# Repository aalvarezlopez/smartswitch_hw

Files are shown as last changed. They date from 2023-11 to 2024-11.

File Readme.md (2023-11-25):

# Issues found while testing the first version

* Resisor package is 0201, change it to 0603
* I2C pins are located in a invalid pin. Correct location is:
   * TWD0 SPI\_SDA => PA3 
   * TWCK SPI\_CLK PA4
* I2C pull up resistors are missed (4k7)
* SPI pins are located in a invalid pin. Correct location is:
    * MISO => PA12
    * MOSI => PA13
    * SPCK => PA14
* DS18B20 can be serialized. Hot/Cold temperature of each radiator could use the same bus

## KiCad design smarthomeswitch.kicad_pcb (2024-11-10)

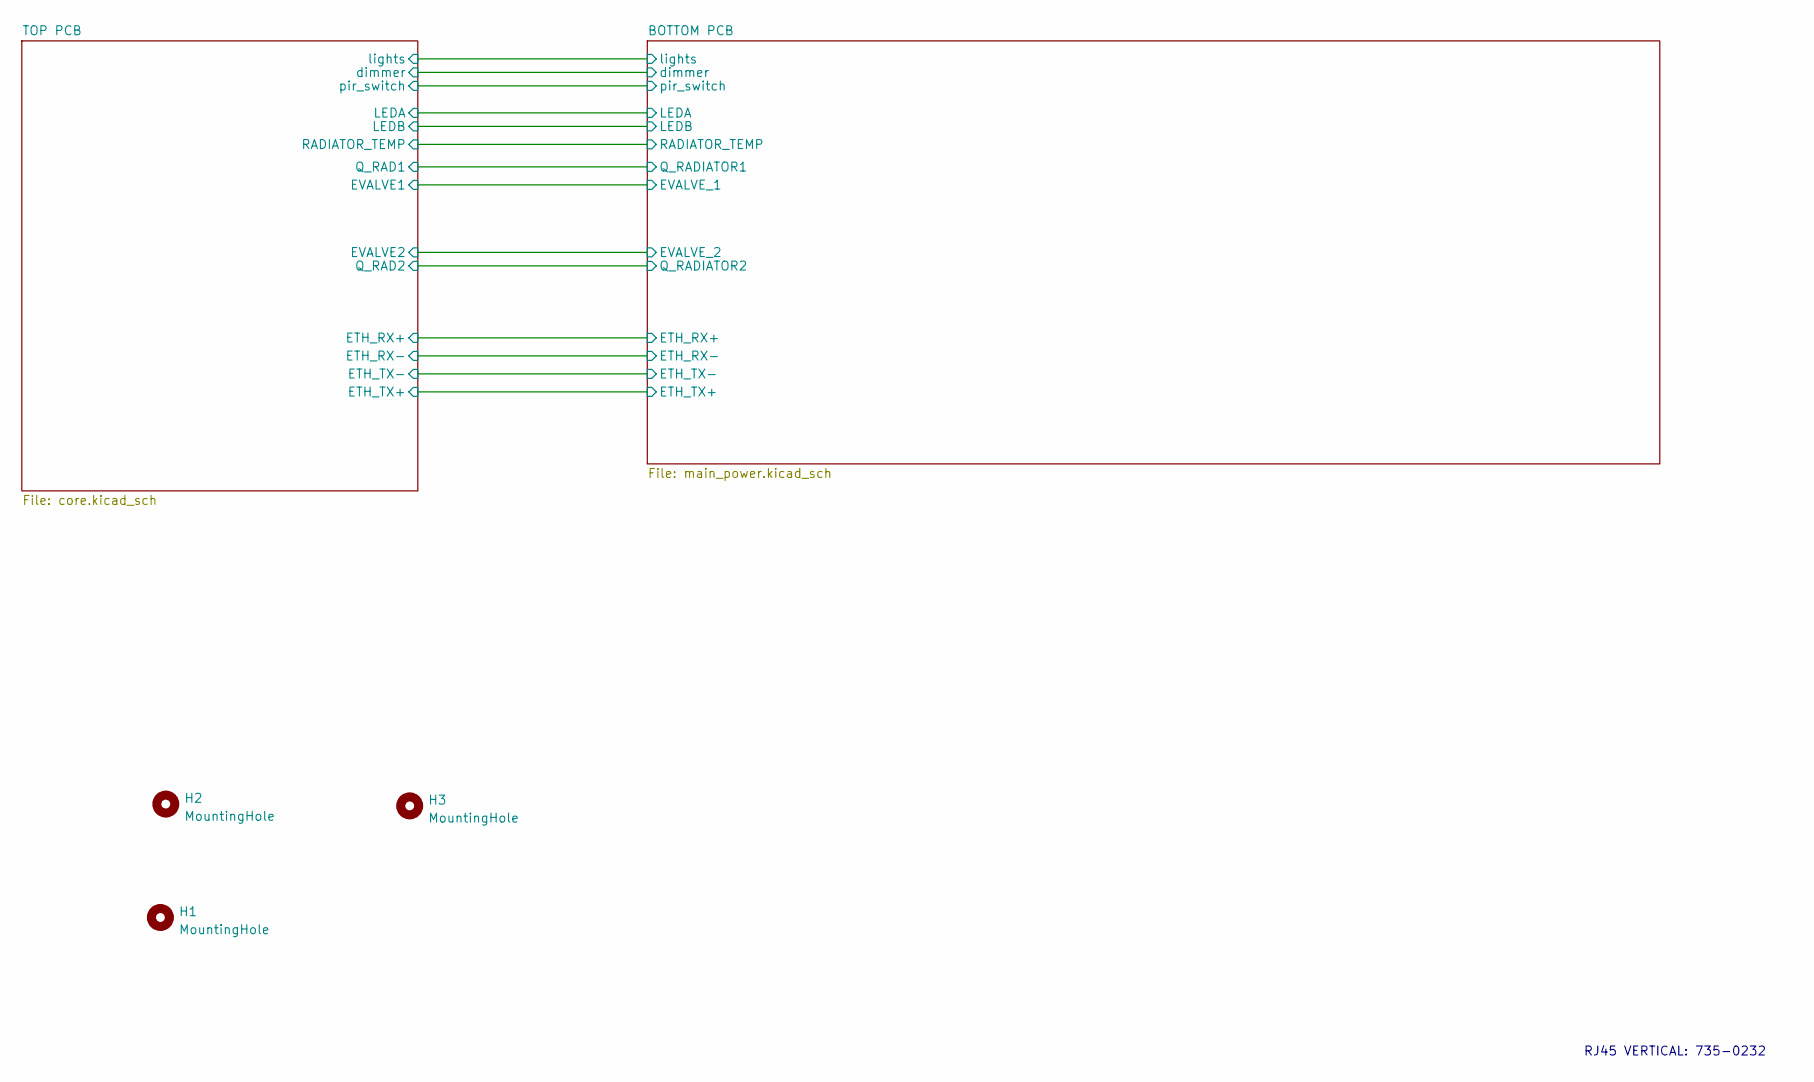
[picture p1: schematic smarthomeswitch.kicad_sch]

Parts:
H1, H2, H3: MountingHole; MountingHole_3.2mm_M3_ISO14580

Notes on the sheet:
RJ45 VERTICAL: 735-0232

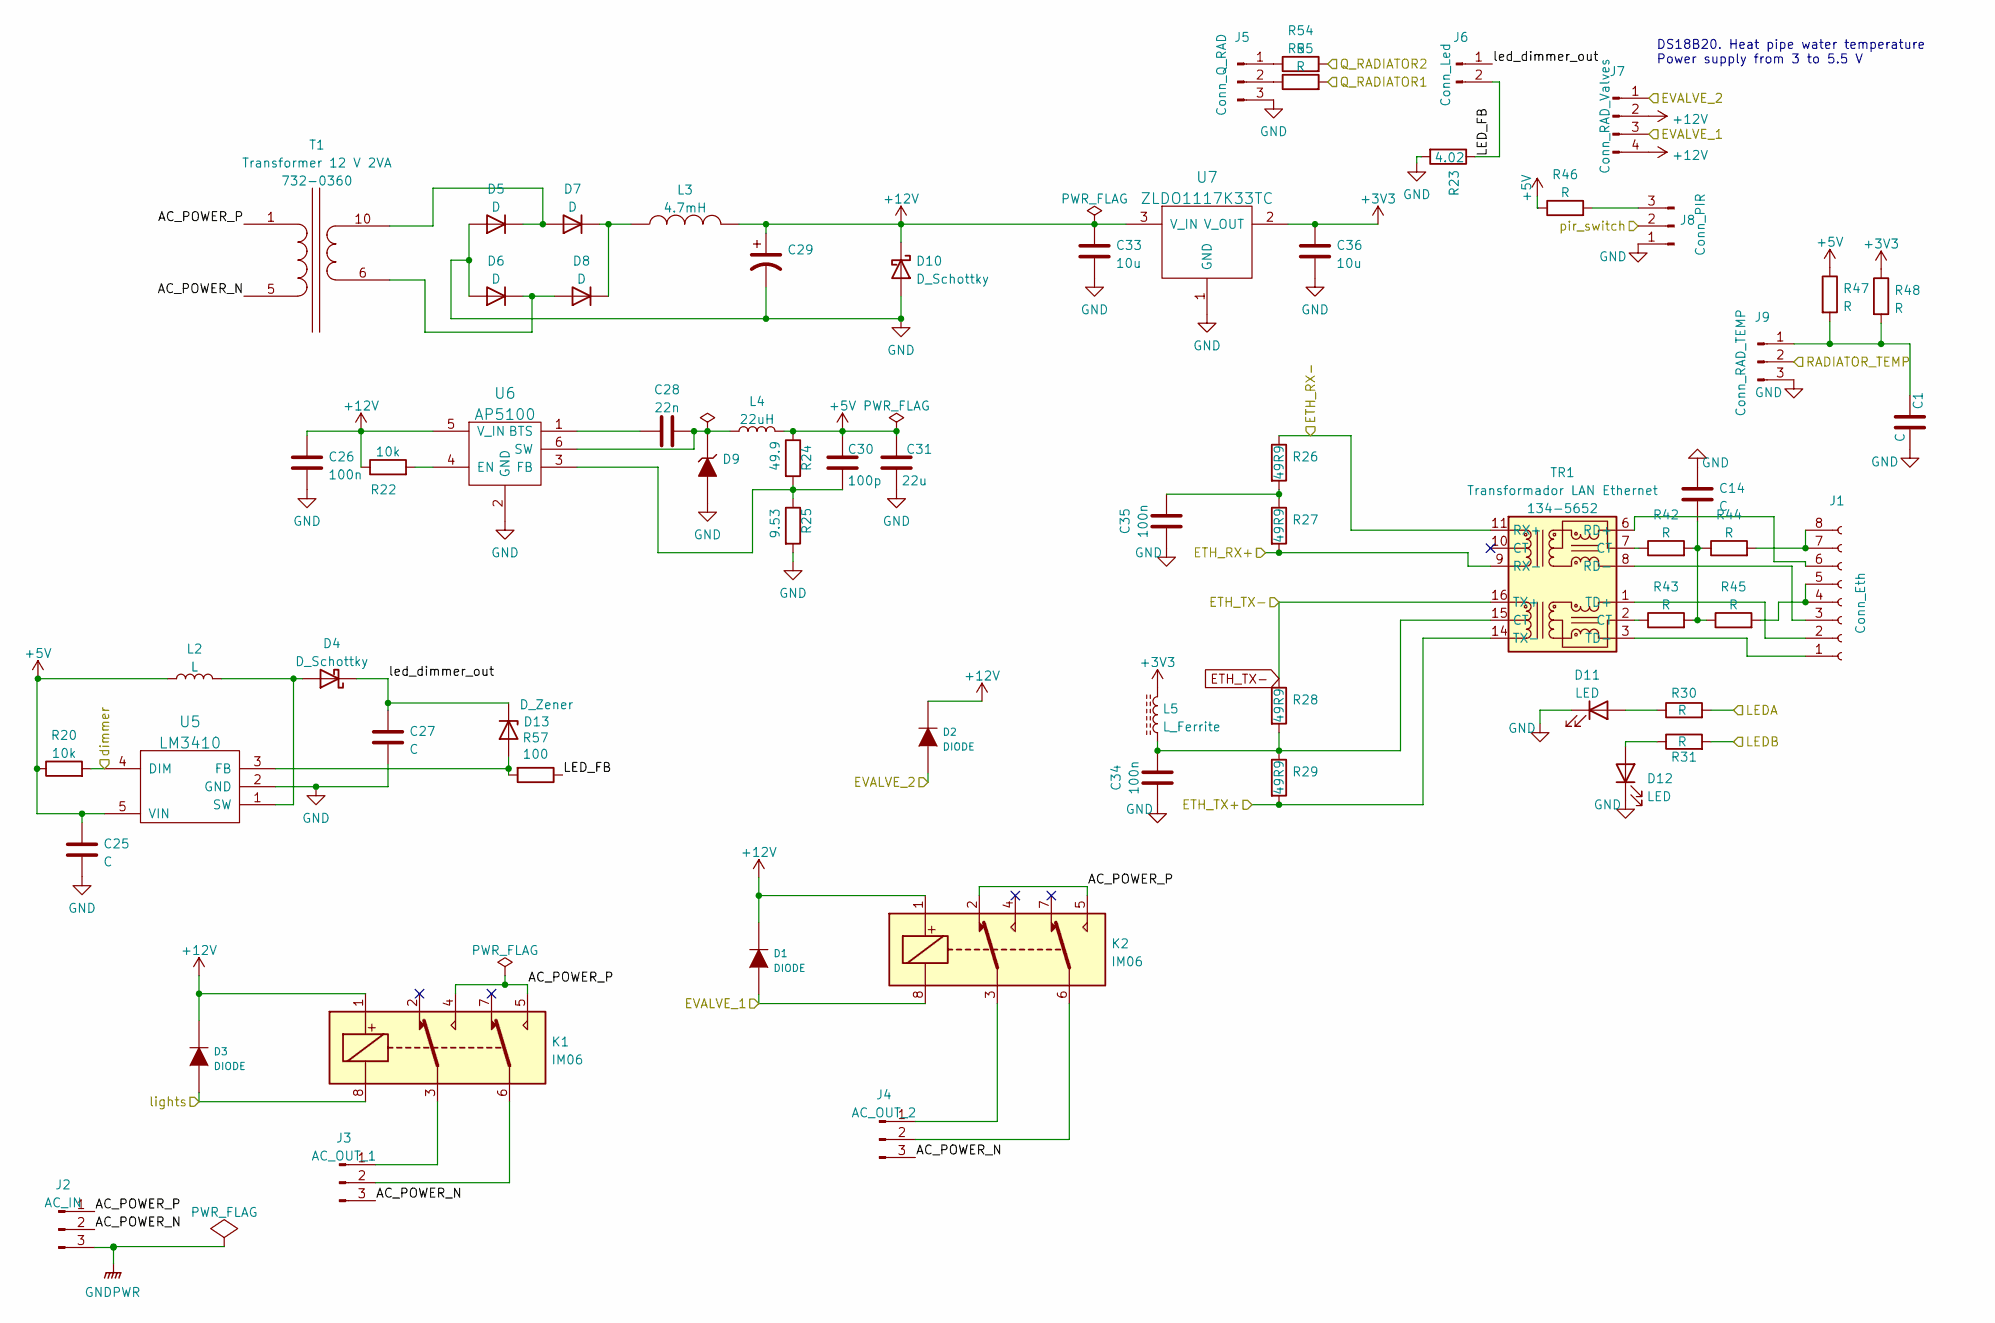
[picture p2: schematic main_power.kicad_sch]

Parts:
C1, C14, C25, C27: C; C_0603_1608Metric_Pad1.08x0.95mm_HandSolder
C26, C34, C35: 100n; C_0603_1608Metric_Pad1.08x0.95mm_HandSolder
C28: 22n; C_0603_1608Metric_Pad1.08x0.95mm_HandSolder
C29: C_Polarized_US; CP_Elec_6.3x5.8
C30: 100p; C_0603_1608Metric_Pad1.08x0.95mm_HandSolder
C31: 22u; CP_EIA-6032-15_Kemet-U_Pad2.25x2.35mm_HandSolder
C33, C36: 10u; CP_EIA-3528-12_Kemet-T_Pad1.50x2.35mm_HandSolder
D1, D2, D3: DIODE; D_SMA
D4: D_Schottky; D_Powermite2_AK
D5, D6, D7, D8: D; DO-213AB
D9: ZENER; D_SOD-323
D10: D_Schottky; D_SMA
D11, D12: LED; LED_0603_1608Metric_Pad1.05x0.95mm_HandSolder
D13: D_Zener; D_SMA_Handsoldering
J1: Conn_Eth; PinHeader_1x08_P2.54mm_Vertical
J2: AC_IN; TerminalBlock_bornier-3_P5.08mm
J3: AC_OUT_1; TerminalBlock_bornier-3_P5.08mm
J4: AC_OUT_2; TerminalBlock_bornier-3_P5.08mm
J5: Conn_Q_RAD; JST_PH_B3B-PH-K_1x03_P2.00mm_Vertical
J6: Conn_Led; JST_PH_B2B-PH-K_1x02_P2.00mm_Vertical
J7: Conn_RAD_Valves; JST_PH_B4B-PH-K_1x04_P2.00mm_Vertical
J8: Conn_PIR; JST_PH_B3B-PH-K_1x03_P2.00mm_Vertical
J9: Conn_RAD_TEMP; JST_PH_B3B-PH-K_1x03_P2.00mm_Vertical
K1, K2: IM06; IM06CTS
L2: L; L_1210_3225Metric_Pad1.42x2.65mm_HandSolder
L3: 4.7mH; L_12x12mm_H8mm
L4: 22uH; L_Wuerth_WE-PD2-Typ-L
L5: L_Ferrite; L_0805_2012Metric_Pad1.15x1.40mm_HandSolder
R20, R22: 10k; R_0603_1608Metric_Pad0.98x0.95mm_HandSolder
R23: 4.02; R_0603_1608Metric_Pad0.98x0.95mm_HandSolder
R24: 49.9; R_0603_1608Metric_Pad0.98x0.95mm_HandSolder
R25: 9.53; R_0603_1608Metric_Pad0.98x0.95mm_HandSolder
R26, R27, R28, R29: 49R9; R_0603_1608Metric_Pad0.98x0.95mm_HandSolder
R30, R31, R42, R43, R44, R45, R46, R47, R48, R54, R55: R; R_0603_1608Metric_Pad0.98x0.95mm_HandSolder
R57: 100; R_0603_1608Metric_Pad0.98x0.95mm_HandSolder
T1: Transformer 12 V 2VA; 12v_transformer_single
TR1: Transformador LAN Ethernet; SM13072APEL
U5: LM3410; SOT-23-5_HandSoldering
U6: AP5100; SOT26
U7: ZLDO1117K33TC; TO-252-3_TabPin2

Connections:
+3V3: C36.1, L5.2, R48.1, U7.2 (V_OUT); also elsewhere on the board
+5V: C25.1, C30.1, C31.1, L2.1, L4.2, R20.1, R24.1, R46.1, R47.1, U5.5 (VIN)
+12V: C26.1, C29.1, C33.1, D1.2 (K), D2.2 (K), D3.2 (K), D10.1 (K), J7.2, J7.4, K1.1, K2.1, L3.2, R22.1, U6.5 (V_IN), U7.3 (V_IN)
/BOTTOM PCB/AC_POWER_N: J2.2, J3.3, J4.3, T1.5 (AB)
/BOTTOM PCB/AC_POWER_P: J2.1, K1.4, K1.5, K2.2, K2.5, T1.1 (AA)
/BOTTOM PCB/EVALVE_1: D1.1 (A), J7.3, K2.8; also elsewhere on the board
/BOTTOM PCB/EVALVE_2: D2.1 (A), J7.1; also elsewhere on the board
/BOTTOM PCB/LEDA: R30.2; also elsewhere on the board
/BOTTOM PCB/LEDB: R31.2; also elsewhere on the board
/BOTTOM PCB/LED_FB: J6.2, R23.1, R57.1
/BOTTOM PCB/Q_RADIATOR1: R55.2; also elsewhere on the board
/BOTTOM PCB/Q_RADIATOR2: R54.2; also elsewhere on the board
/BOTTOM PCB/RADIATOR_TEMP: J9.2; also elsewhere on the board
/BOTTOM PCB/dimmer: R20.2, U5.4 (DIM); also elsewhere on the board
/BOTTOM PCB/led_dimmer_out: C27.1, D4.1 (K), D13.1 (K), J6.1
/BOTTOM PCB/lights: D3.1 (A), K1.8; also elsewhere on the board
/BOTTOM PCB/pir_switch: J8.2; also elsewhere on the board
/TOP PCB/ethernet/ETH_RX+: R27.2, TR1.9 (RX-); also elsewhere on the board
/TOP PCB/ethernet/ETH_RX-: R26.1, TR1.11 (RX+); also elsewhere on the board
/TOP PCB/ethernet/ETH_TX+: R29.2, TR1.14 (TX-); also elsewhere on the board
ETH_TX-: R28.1, TR1.16 (TX+); also elsewhere on the board
GND: C1.2, C14.1, C25.2, C26.2, C27.2, C29.2, C31.2, C33.2, C34.1, C35.1, C36.2, D5.2 (A), D6.2 (A), D9.2 (A), D10.2 (A), D11.1 (K), D12.1 (K), J5.3, J8.1, J9.3, R23.2, R25.2, U5.2 (GND), U6.2 (GND), U7.1 (GND); also elsewhere on the board
GNDPWR: J2.3
unnamed: C1.1, J9.1, R47.2, R48.2
unnamed: C14.2, R42.2, R43.2, R44.1, R45.1
unnamed: C28.1, U6.1 (BTS)
unnamed: C28.2, D9.1 (K), L4.1, U6.6 (SW)
unnamed: C30.2, R24.2, R25.1, U6.3 (FB)
unnamed: C34.2, L5.1, R28.2, R29.1, TR1.15 (CT)
unnamed: C35.2, R26.2, R27.1
unnamed: D4.2 (A), L2.2, U5.1 (SW)
unnamed: D5.1 (K), D7.2 (A), T1.10 (SA)
unnamed: D6.1 (K), D8.2 (A), T1.6 (SD)
unnamed: D7.1 (K), D8.1 (K), L3.1
unnamed: D11.2 (A), R30.1
unnamed: D12.2 (A), R31.1
unnamed: D13.2 (A), R57.2, U5.3 (FB)
unnamed: J1.1, TR1.3 (TD-)
unnamed: J1.2, TR1.1 (TD+)
unnamed: J1.3, TR1.8 (RD-)
unnamed: J1.4, J1.5, R45.2
unnamed: J1.6, TR1.6 (RD+)
unnamed: J1.7, J1.8, R44.2
unnamed: J3.1, K1.3
unnamed: J3.2, K1.6
unnamed: J4.1, K2.3
unnamed: J4.2, K2.6
unnamed: J5.1, R54.1
unnamed: J5.2, R55.1
unnamed: J8.3, R46.2
unnamed: R22.2, U6.4 (EN)
unnamed: R42.1, TR1.7 (CT)
unnamed: R43.1, TR1.2 (CT)

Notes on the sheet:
DS18B20. Heat pipe water temperature Power supply from 3 to 5.5 V

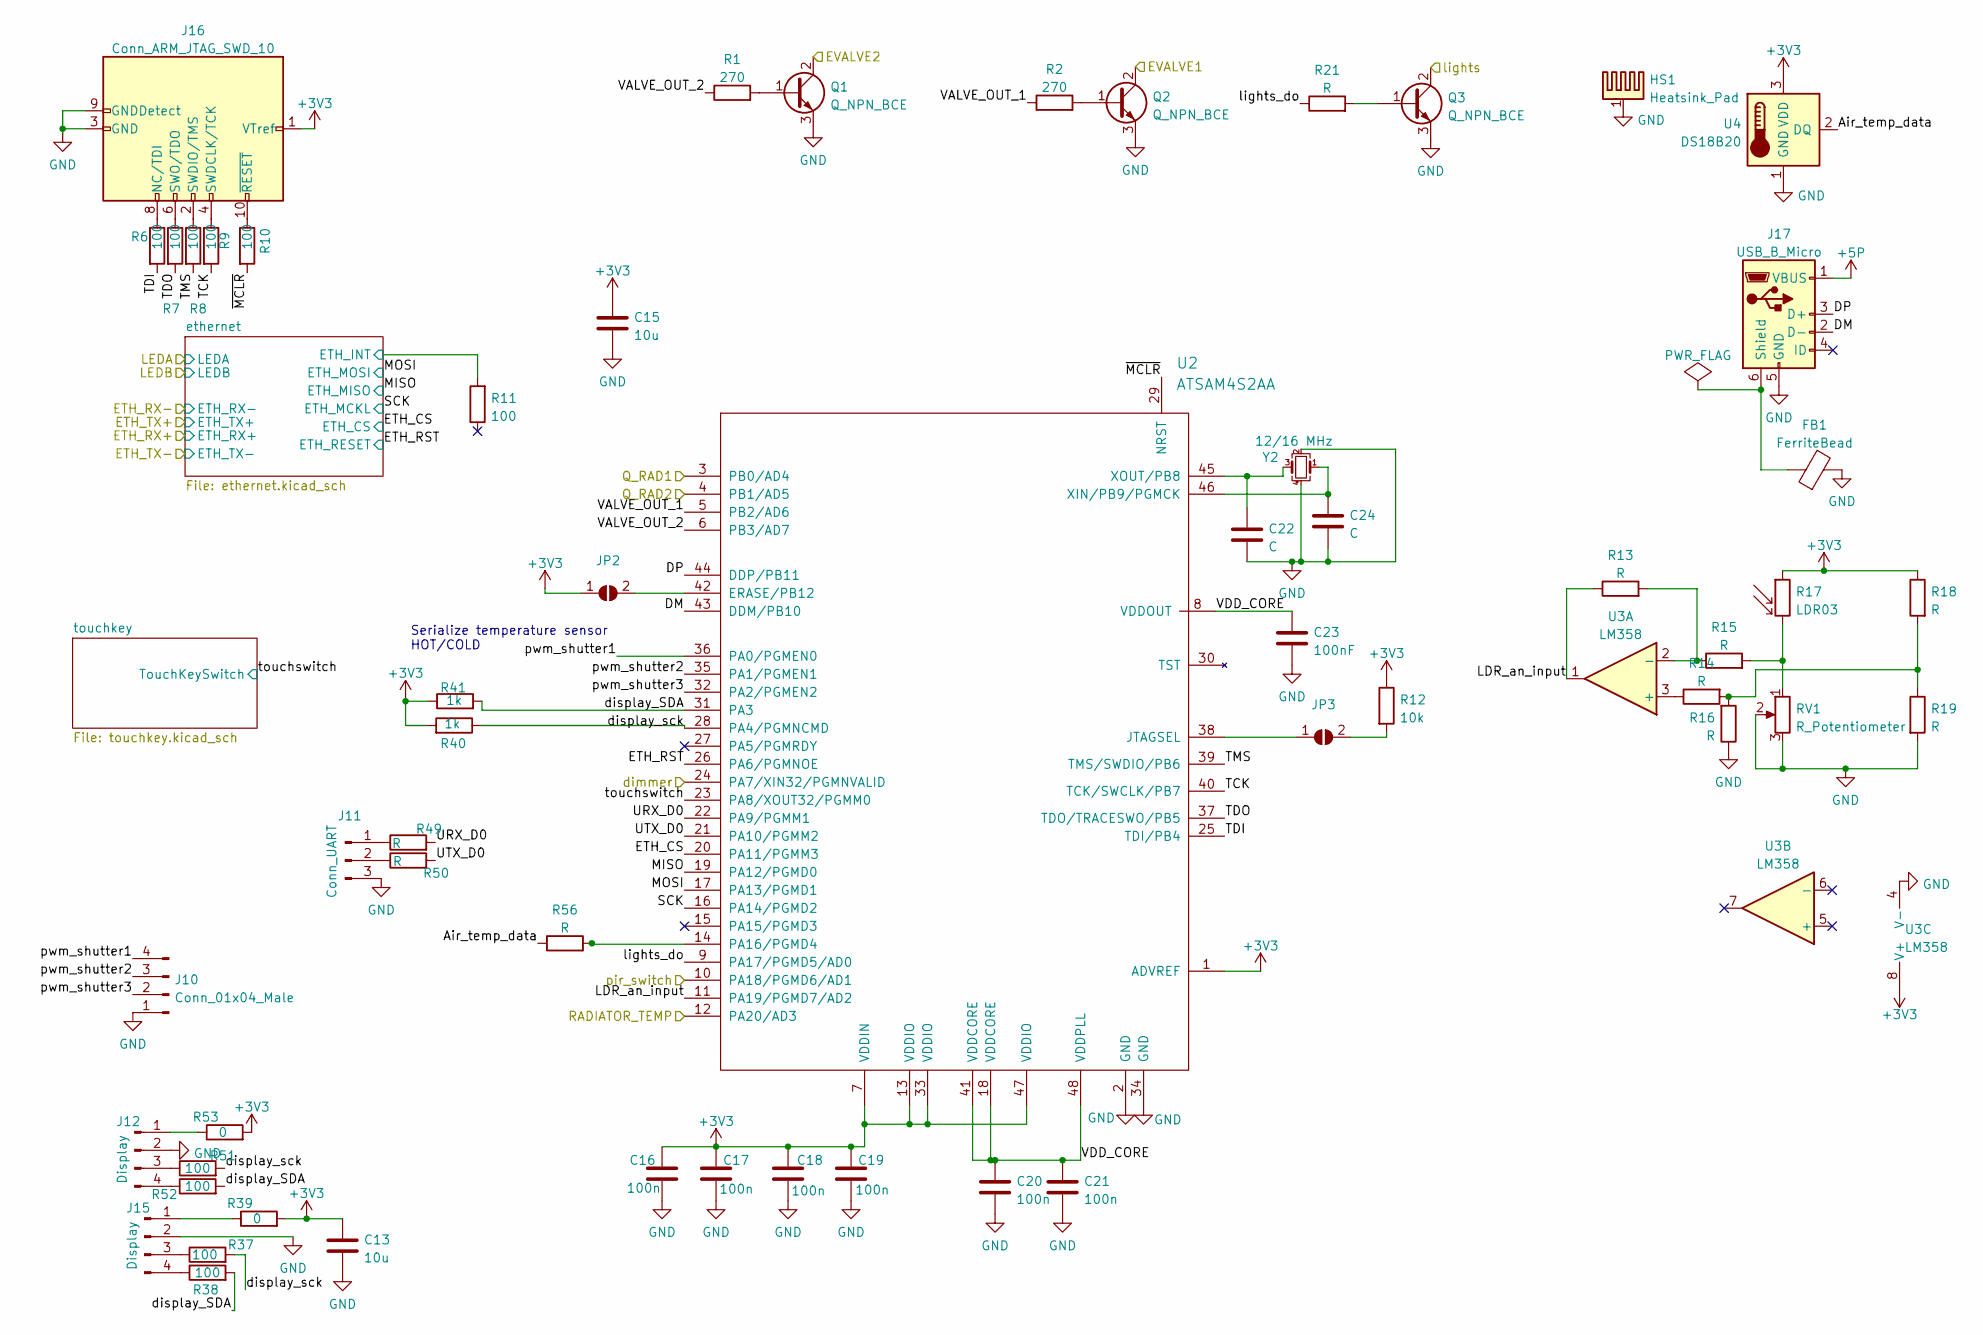
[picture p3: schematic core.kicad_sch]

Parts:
C13, C15: 10u; CP_EIA-3528-12_Kemet-T_Pad1.50x2.35mm_HandSolder
C16, C17, C18, C19, C20, C21: 100n; C_0603_1608Metric_Pad1.08x0.95mm_HandSolder
C22, C24: C; C_0603_1608Metric_Pad1.08x0.95mm_HandSolder
C23: 100nF; C_0603_1608Metric_Pad1.08x0.95mm_HandSolder
FB1: FerriteBead; L_1206_3216Metric_Pad1.22x1.90mm_HandSolder
HS1: Heatsink_Pad; Heatsink_AAVID_573300D00010G_TO-263
J10: Conn_01x04_Male; JST_PH_B4B-PH-K_1x04_P2.00mm_Vertical
J11: Conn_UART; JST_PH_B3B-PH-K_1x03_P2.00mm_Vertical
J12, J15: Display; PinHeader_1x04_P2.54mm_Vertical
J16: Conn_ARM_JTAG_SWD_10; JTAG_50mil
J17: USB_B_Micro; USB_Micro-B_Molex_47346-0001
JP2, JP3: SolderJumper_2_Open; SolderJumper-2_P1.3mm_Open_TrianglePad1.0x1.5mm
Q1, Q2, Q3: Q_NPN_BCE; SOT-223-3_TabPin2
R1, R2: 270; R_0603_1608Metric_Pad0.98x0.95mm_HandSolder
R6, R7, R8, R9, R10, R11, R37, R38, R51, R52: 100; R_0603_1608Metric_Pad0.98x0.95mm_HandSolder
R12: 10k; R_0603_1608Metric_Pad0.98x0.95mm_HandSolder
R13, R14, R15, R16, R18, R19, R21, R49, R50, R56: R; R_0603_1608Metric_Pad0.98x0.95mm_HandSolder
R17: LDR03; R_Axial_DIN0204_L3.6mm_D1.6mm_P1.90mm_Vertical
R39, R53: 0; R_0603_1608Metric_Pad0.98x0.95mm_HandSolder
R40, R41: 1k; R_0603_1608Metric_Pad0.98x0.95mm_HandSolder
RV1: R_Potentiometer; Potentiometer_Bourns_TC33X_Vertical
U2: ATSAM4S2AA; LQFP-48_7x7mm_P0.5mm
U3: LM358; SOIC-8_3.9x4.9mm_P1.27mm
U4: DS18B20; TO-92_Inline
Y2: 12/16 MHz; Crystal_SMD_5032-4Pin_5.0x3.2mm

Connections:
+3V3: C13.1, C15.1, C16.1, C17.1, C18.1, C19.1, J16.1 (VTref), JP2.1 (A), R12.1, R17.1, R18.1, R39.2, R40.2, R41.1, R53.2, U2.1 (ADVREF), U2.7 (VDDIN), U2.13 (VDDIO), U2.33 (VDDIO), U2.47 (VDDIO), U3.8 (V+), U4.3 (VDD); also elsewhere on the board
+5P: J17.1 (VBUS)
/BOTTOM PCB/EVALVE_1: Q2.2 (C); also elsewhere on the board
/BOTTOM PCB/EVALVE_2: Q1.2 (C); also elsewhere on the board
/BOTTOM PCB/Q_RADIATOR1: U2.3 (PB0/AD4); also elsewhere on the board
/BOTTOM PCB/Q_RADIATOR2: U2.4 (PB1/AD5); also elsewhere on the board
/BOTTOM PCB/RADIATOR_TEMP: U2.12 (PA20/AD3); also elsewhere on the board
/BOTTOM PCB/dimmer: U2.24 (PA7/XIN32/PGMNVALID); also elsewhere on the board
/BOTTOM PCB/lights: Q3.2 (C); also elsewhere on the board
/BOTTOM PCB/pir_switch: U2.10 (PA18/PGMD6/AD1); also elsewhere on the board
/TOP PCB/Air_temp_data: R56.1, U4.2 (DQ)
/TOP PCB/DM: J17.2 (D-), U2.43 (DDM/PB10)
/TOP PCB/DP: J17.3 (D+), U2.44 (DDP/PB11)
/TOP PCB/ETH_CS: U2.20 (PA11/PGMM3); also elsewhere on the board
/TOP PCB/ETH_RST: U2.26 (PA6/PGMNOE); also elsewhere on the board
/TOP PCB/LDR_an_input: R13.1, U2.11 (PA19/PGMD7/AD2), U3.1
/TOP PCB/MISO: U2.19 (PA12/PGMD0); also elsewhere on the board
/TOP PCB/MOSI: U2.17 (PA13/PGMD1); also elsewhere on the board
/TOP PCB/SCK: U2.16 (PA14/PGMD2); also elsewhere on the board
/TOP PCB/TCK: R9.2, U2.40 (TCK/SWCLK/PB7)
/TOP PCB/TDI: R6.2, U2.25 (TDI/PB4)
/TOP PCB/TDO: R7.2, U2.37 (TDO/TRACESWO/PB5)
/TOP PCB/TMS: R8.2, U2.39 (TMS/SWDIO/PB6)
/TOP PCB/URX_D0: R49.2, U2.22 (PA9/PGMM1)
/TOP PCB/UTX_D0: R50.2, U2.21 (PA10/PGMM2)
/TOP PCB/VALVE_OUT_1: R2.1, U2.5 (PB2/AD6)
/TOP PCB/VALVE_OUT_2: R1.1, U2.6 (PB3/AD7)
/TOP PCB/VDD_CORE: C20.1, C21.1, C23.1, U2.8 (VDDOUT), U2.18 (VDDCORE), U2.41 (VDDCORE), U2.48 (VDDPLL)
/TOP PCB/display_SDA: R38.2, R41.2, R52.2, U2.31 (PA3)
/TOP PCB/display_sck: R37.2, R40.1, R51.2, U2.28 (PA4/PGMNCMD)
/TOP PCB/ethernet/ETH_INT: R11.2; also elsewhere on the board
/TOP PCB/lights_do: R21.1, U2.9 (PA17/PGMD5/AD0)
/TOP PCB/pwm_shutter1: J10.4, U2.36 (PA0/PGMEN0)
/TOP PCB/pwm_shutter2: J10.3, U2.35 (PA1/PGMEN1)
/TOP PCB/pwm_shutter3: J10.2, U2.32 (PA2/PGMEN2)
/TOP PCB/touchswitch: U2.23 (PA8/XOUT32/PGMM0); also elsewhere on the board
/TOP PCB/~MCLR: R10.2, U2.29 (NRST)
GND: C13.2, C15.2, C16.2, C17.2, C18.2, C19.2, C20.2, C21.2, C22.2, C23.2, C24.2, FB1.2, HS1.1, J10.1, J11.3, J12.2, J15.2, J16.3 (GND), J16.5 (GND), J16.9 (GNDDetect), J17.5 (GND), Q1.3 (E), Q2.3 (E), Q3.3 (E), R16.1, R19.2, RV1.2, RV1.3, U2.2 (GND), U2.34 (GND), U3.4 (V-), U4.1 (GND), Y2.2, Y2.4; also elsewhere on the board
unnamed: C22.1, U2.45 (XOUT/PB8), Y2.3
unnamed: C24.1, U2.46 (XIN/PB9/PGMCK), Y2.1
unnamed: FB1.1, J17.6 (Shield)
unnamed: J11.1, R49.1
unnamed: J11.2, R50.1
unnamed: J12.1, R53.1
unnamed: J12.3, R51.1
unnamed: J12.4, R52.1
unnamed: J15.1, R39.1
unnamed: J15.3, R37.1
unnamed: J15.4, R38.1
unnamed: J16.2 (SWDIO/TMS), R8.1
unnamed: J16.4 (SWDCLK/TCK), R9.1
unnamed: J16.6 (SWO/TDO), R7.1
unnamed: J16.8 (NC/TDI), R6.1
unnamed: J16.10 (~RESET), R10.1
unnamed: JP2.2 (B), U2.42 (ERASE/PB12)
unnamed: JP3.1 (A), U2.38 (JTAGSEL)
unnamed: JP3.2 (B), R12.2
unnamed: Q1.1 (B), R1.2
unnamed: Q2.1 (B), R2.2
unnamed: Q3.1 (B), R21.2
unnamed: R13.2, R15.1, U3.2 (-)
unnamed: R14.1, U3.3 (+)
unnamed: R14.2, R16.2, R18.2, R19.1
unnamed: R15.2, R17.2, RV1.1
unnamed: R56.2, U2.14 (PA16/PGMD4)

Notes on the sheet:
Serialize temperature sensor HOT/COLD

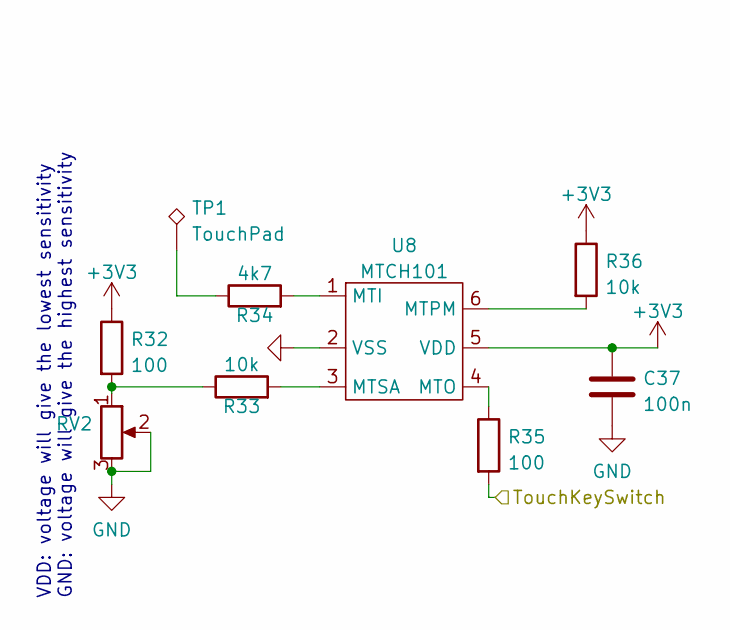
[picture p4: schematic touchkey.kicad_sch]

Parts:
C37: 100n; C_0603_1608Metric_Pad1.08x0.95mm_HandSolder
R32, R35: 100; R_0603_1608Metric_Pad0.98x0.95mm_HandSolder
R33, R36: 10k; R_0603_1608Metric_Pad0.98x0.95mm_HandSolder
R34: 4k7; R_0603_1608Metric_Pad0.98x0.95mm_HandSolder
RV2: R_Potentiometer; Potentiometer_Bourns_TC33X_Vertical
TP1: TouchPad; SolderWire-0.15sqmm_1x01_D0.5mm_OD1.5mm
U8: MTCH101; SOT-23-6_Handsoldering

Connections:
+3V3: C37.1, R32.1, R36.1, U8.5 (VDD); also elsewhere on the board
/TOP PCB/touchswitch: R35.2; also elsewhere on the board
GND: C37.2, RV2.2, RV2.3, U8.2 (VSS); also elsewhere on the board
unnamed: R32.2, R33.1, RV2.1
unnamed: R33.2, U8.3 (MTSA)
unnamed: R34.1, TP1.1
unnamed: R34.2, U8.1 (MTI)
unnamed: R35.1, U8.4 (MTO)
unnamed: R36.2, U8.6 (MTPM)

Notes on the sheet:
VDD: voltage will give the lowest sensitivity GND: voltage will give the highest sensitivity

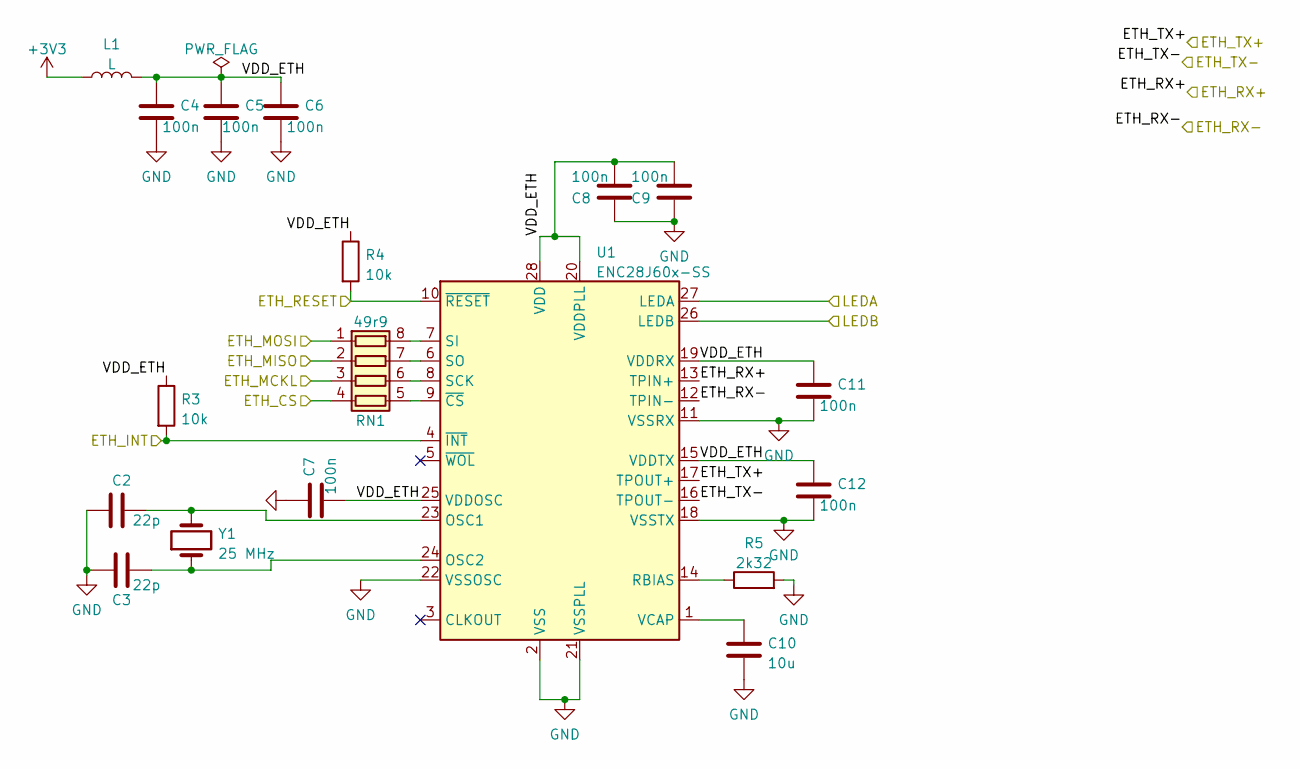
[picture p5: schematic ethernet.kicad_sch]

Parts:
C2, C3: 22p; C_0603_1608Metric_Pad1.08x0.95mm_HandSolder
C4, C5, C6, C7, C8, C9, C11, C12: 100n; C_0603_1608Metric_Pad1.08x0.95mm_HandSolder
C10: 10u; CP_EIA-3528-21_Kemet-B_Pad1.50x2.35mm_HandSolder
L1: L; L_0603_1608Metric_Pad1.05x0.95mm_HandSolder
R3, R4: 10k; R_0603_1608Metric_Pad0.98x0.95mm_HandSolder
R5: 2k32; R_0603_1608Metric_Pad0.98x0.95mm_HandSolder
RN1: 49r9; R_Array_Convex_4x0612
U1: ENC28J60x-SS; SSOP-28_5.3x10.2mm_P0.65mm
Y1: 25 MHz; Crystal_SMD_HC49-SD

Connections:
+3V3: L1.1; also elsewhere on the board
/BOTTOM PCB/LEDA: U1.27 (LEDA); also elsewhere on the board
/BOTTOM PCB/LEDB: U1.26 (LEDB); also elsewhere on the board
/TOP PCB/ETH_CS: RN1.4 (R4.1); also elsewhere on the board
/TOP PCB/ETH_RST: R4.2, U1.10 (~RESET); also elsewhere on the board
/TOP PCB/MISO: RN1.2 (R2.1); also elsewhere on the board
/TOP PCB/MOSI: RN1.1 (R1.1); also elsewhere on the board
/TOP PCB/SCK: RN1.3 (R3.1); also elsewhere on the board
/TOP PCB/ethernet/ETH_INT: R3.2, U1.4 (~INT); also elsewhere on the board
/TOP PCB/ethernet/ETH_RX+: U1.13 (TPIN+); also elsewhere on the board
/TOP PCB/ethernet/ETH_RX-: U1.12 (TPIN-); also elsewhere on the board
/TOP PCB/ethernet/ETH_TX+: U1.17 (TPOUT+); also elsewhere on the board
/TOP PCB/ethernet/VDD_ETH: C4.1, C5.1, C6.1, C7.2, C8.2, C9.2, C11.1, C12.1, L1.2, R3.1, R4.1, U1.15 (VDDTX), U1.19 (VDDRX), U1.20 (VDDPLL), U1.25 (VDDOSC), U1.28 (VDD)
ETH_TX-: U1.16 (TPOUT-); also elsewhere on the board
GND: C2.1, C3.1, C4.2, C5.2, C6.2, C7.1, C8.1, C9.1, C10.2, C11.2, C12.2, R5.2, U1.2 (VSS), U1.11 (VSSRX), U1.18 (VSSTX), U1.21 (VSSPLL), U1.22 (VSSOSC); also elsewhere on the board
unnamed: C2.2, U1.23 (OSC1), Y1.2
unnamed: C3.2, U1.24 (OSC2), Y1.1
unnamed: C10.1, U1.1 (VCAP)
unnamed: R5.1, U1.14 (RBIAS)
unnamed: RN1.5 (R4.2), U1.9 (~CS)
unnamed: RN1.6 (R3.2), U1.8 (SCK)
unnamed: RN1.7 (R2.2), U1.6 (SO)
unnamed: RN1.8 (R1.2), U1.7 (SI)

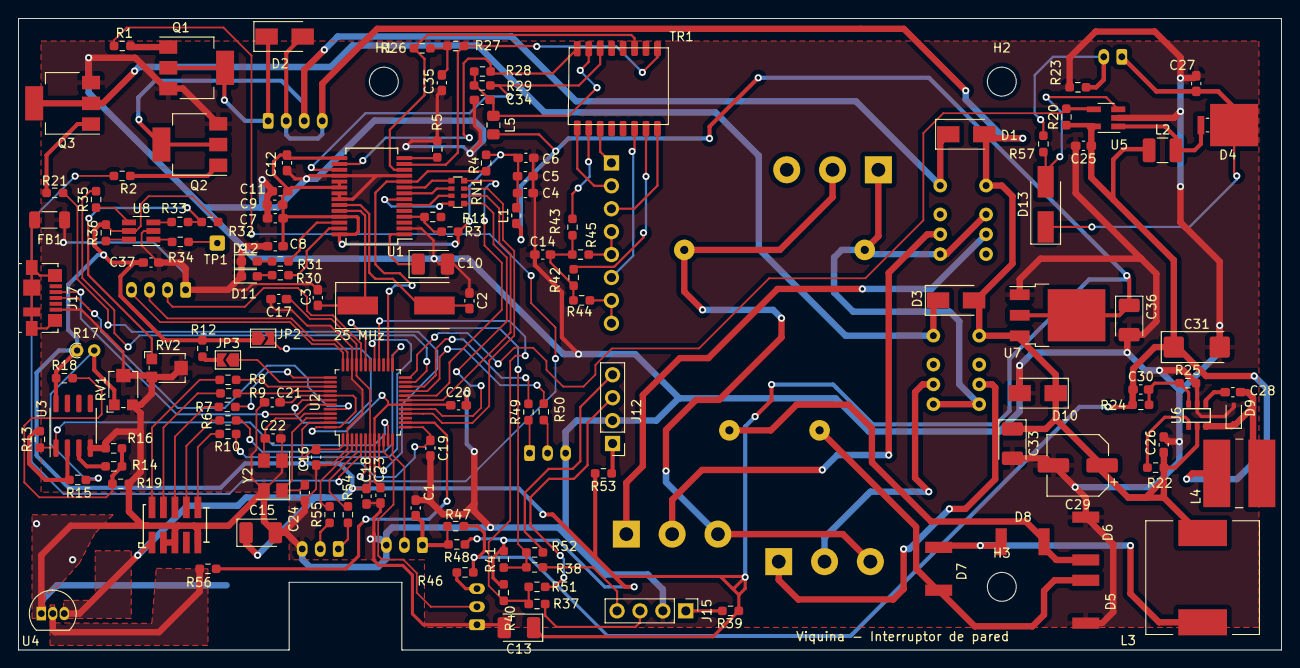
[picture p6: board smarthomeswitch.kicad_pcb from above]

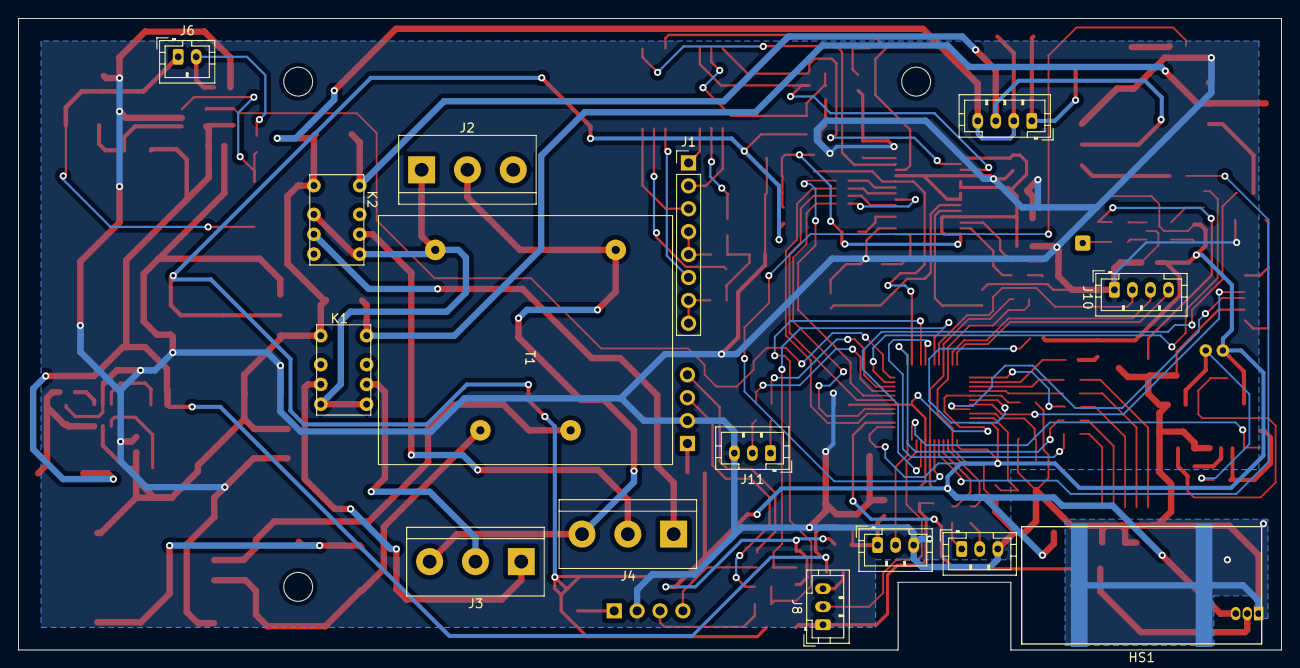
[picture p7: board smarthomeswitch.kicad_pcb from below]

Board: 2 copper layers, 140.0 x 70.0 mm, 154 parts (15 on the bottom side), 121 nets.

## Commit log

2023-11-25 First commit. First version with lot of issues
    [ethernet.kicad_sch, power.kicad_sch, radiator.kicad_sch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]
2024-11-10 Second version
    [ethernet.kicad_sch, power.kicad_sch, radiator.kicad_sch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]
2024-11-10 Adding subcomponents
    [core.kicad_sch, main_power.kicad_sch]
